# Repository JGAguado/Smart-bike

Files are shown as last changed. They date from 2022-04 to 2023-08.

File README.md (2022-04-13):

[][releases]
[](LICENSE)

[][maintenance]
[][buymecoffee]

# μBike
RP2040 microcontroller based board for standard bikes applications: lights control, GPS location with LoRa telemetry and display unit.

<p float="left">
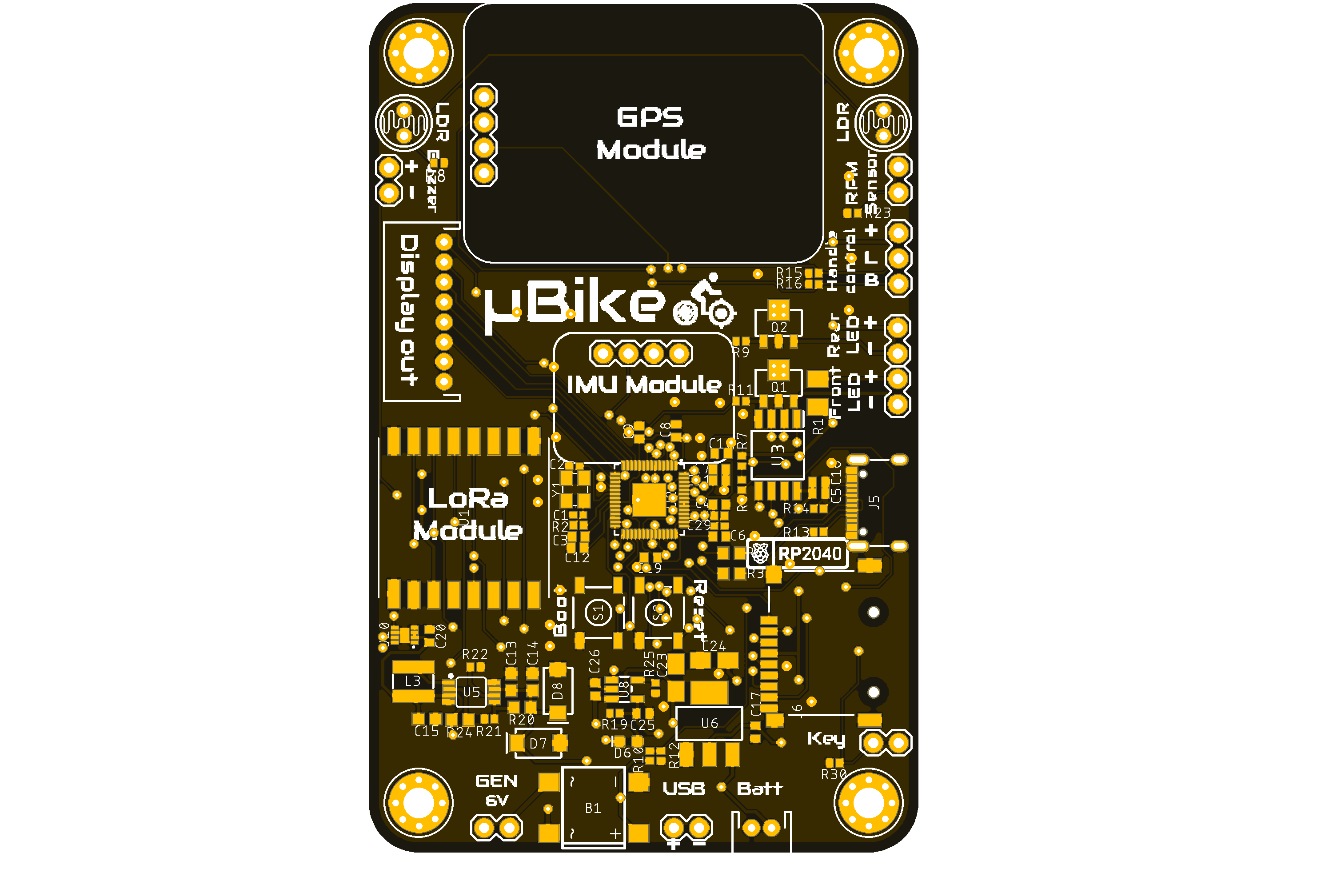
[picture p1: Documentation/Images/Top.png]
   
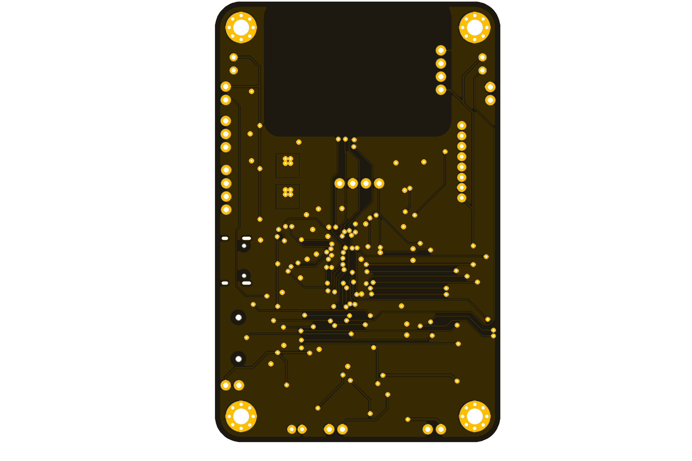
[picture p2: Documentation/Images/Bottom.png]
      
</p>

## Project tree
---

<li><a href="./uBike/Design/">Design</a></li>
<li><a href="./uBike/Documentation/">Documentation</a></li>

<li><a href="./README.md">README.md</a></li>

## Acknowledgments
---
 * [SparkFun Thing Plus RP2040](https://github.com/sparkfun/SparkFun_Thing_Plus-RP2040) - This board was used as inspiration for the layout design of the μBike

[releases-shield]: https://img.shields.io/github/release/JGAguado/uBike.svg?style=for-the-badge
[releases]: https://github.com/JGAguado/Fuel_Tracker/releases

[license-shield]: https://img.shields.io/badge/License-CC%20BY--NC--SA%204.0-lightgrey.svg?style=for-the-badge

[maintenance-shield]: https://img.shields.io/badge/maintainer-J.%20G.%20Aguado-blue.svg?style=for-the-badge
[maintenance]: https://github.com/JGAguado

[buymecoffee-shield]: https://img.shields.io/badge/buy%20me%20a%20coffee-support-yellow.svg?style=for-the-badge
[buymecoffee]: https://www.buymeacoffee.com/J.G.Aguado

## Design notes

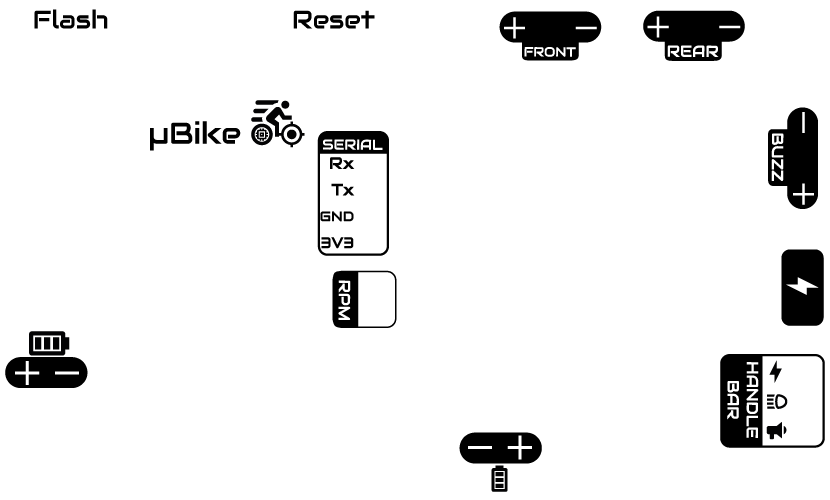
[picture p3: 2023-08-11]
Documentation/Silkscreen/Top.png

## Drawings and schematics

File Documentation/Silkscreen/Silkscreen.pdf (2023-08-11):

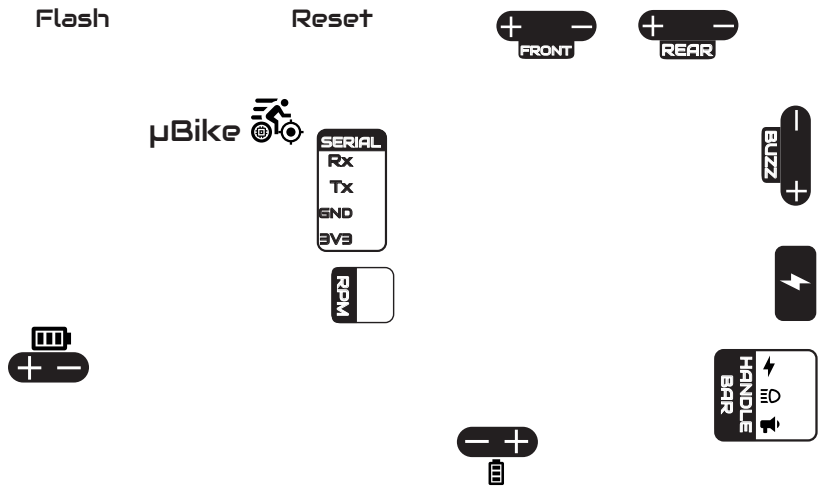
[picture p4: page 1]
Flash; Reset; GND; SERIAL; HANDLE BAR; REAR; BUZZ; FRONT; RPM; µBike

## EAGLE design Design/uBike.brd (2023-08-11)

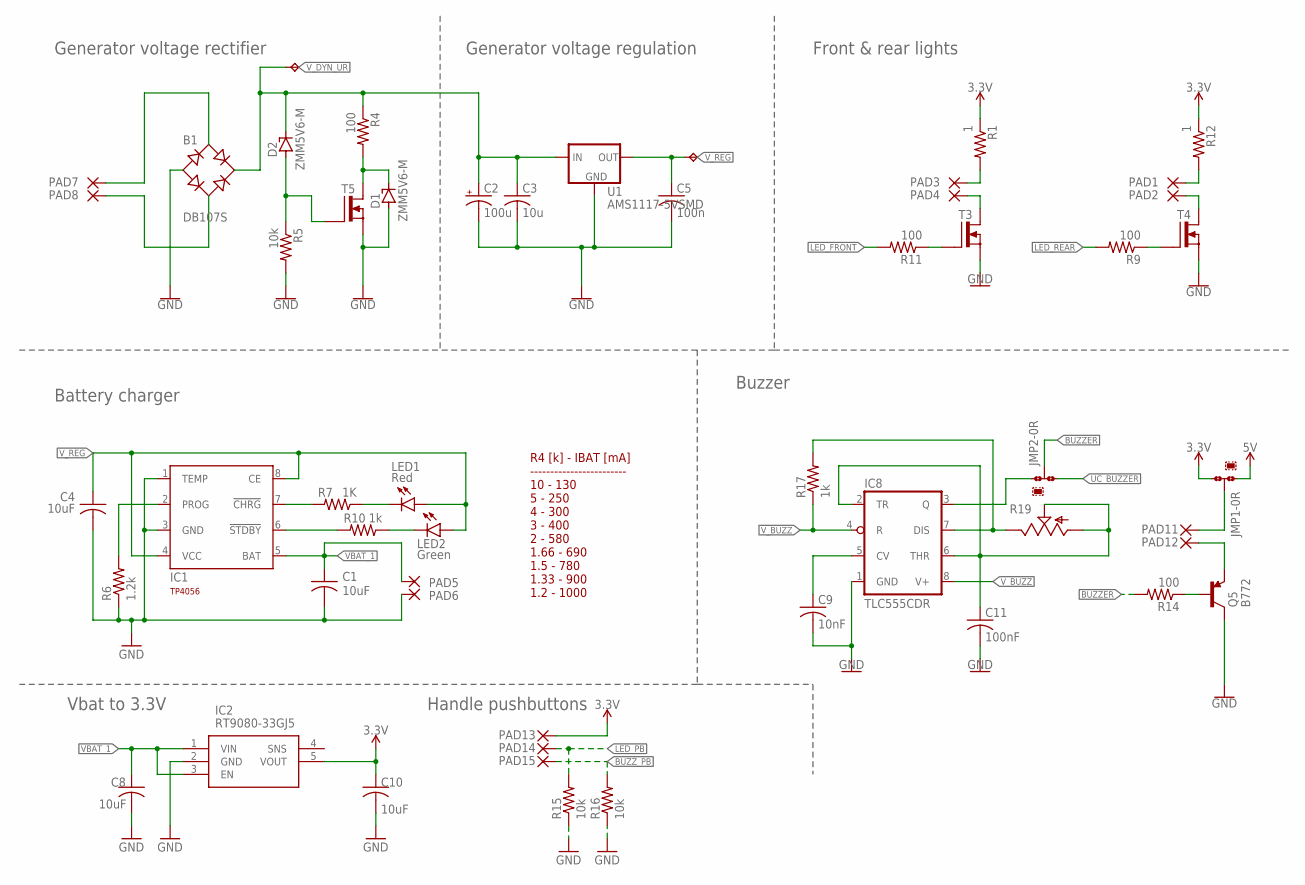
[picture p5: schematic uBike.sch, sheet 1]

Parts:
B1: DB107S; DBS; LCSC C5377
C1, C4, C8, C10: 10uF; C0603
C2: 100u; B/3528-21R; LCSC C16133
C3: 10u; C0603
C5: 100n; C0603
C9: 10nF; C0603
C11: 100nF; C0603
D1, D2: ZMM5V6-M; MELF-MLL34
IC1: TP4056; SOT23-8; LCSC C16581
IC2: RT9080-33GJ5; SOT94P280X100-5N; LCSC C841192
IC8: TLC555CDR; SO08; LCSC C6986
JMP1, JMP2: 0R-JUMPA; A0R-JMP
LED1: Red; LED_0603
LED2: Green; LED_0603
PAD1, PAD2, PAD3, PAD4, PAD5, PAD6, PAD7, PAD8, PAD11, PAD12, PAD13, PAD14, PAD15: SMD2; SMD1,27-2,54
Q5: B772; SOT89; LCSC C24278
R1, R12: 1; R1206; LCSC C17928
R4: 100; 0402; LCSC C17928
R5: 10k; 0402; LCSC C17928
R6: 1.2k; 0402
R7: 1K; 0402
R9, R11, R14: 100; 0402
R10, R17: 1k; 0402
R15, R16: 10k; 0402
R19: TRIM_US-RJ9W; RJ9W
T3, T4, T5: T_N-MOSFET_2N7002_CHANGJ_SOT23-GSD; SOT23
TP1, TP3: TPTP15R; TP15R
U1: AMS1117-5VSMD; SOT223

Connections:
3.3V: C10.1, IC2.5 (VOUT), JMP1.3, PAD13.1, R1.1, R12.1; also elsewhere on the board
5V: JMP1.1
BUZZER: JMP2.2, R14.2
BUZZ_PB: PAD15.1, R16.2; also elsewhere on the board
GND: B1.-, C1.2, C2.-, C3.2, C4.2, C5.2, C8.2, C9.2, C10.2, C11.2, D1.A, IC1.1 (TEMP), IC1.3 (GND), IC2.2 (GND), IC8.1 (GND), PAD6.1, Q5.2 (C), R5.2, R6.1, R15.1, R16.1, T3.2 (S), T4.2 (S), T5.2 (S), U1.1 (GND); also elsewhere on the board
LED_FRONT: R11.2; also elsewhere on the board
LED_PB: PAD14.1, R15.2; also elsewhere on the board
LED_REAR: R9.2; also elsewhere on the board
unnamed: PAD3.1, R1.2
unnamed: R9.1, T4.1 (G)
unnamed: IC1.6 (!STDBY), R10.2
unnamed: PAD4.1, T3.3 (D)
unnamed: R11.1, T3.1 (G)
unnamed: PAD2.1, T4.3 (D)
unnamed: D2.A, R5.1, T5.1 (G)
unnamed: D1.C, R4.2, T5.3 (D)
unnamed: B1.AC2, PAD8.1
unnamed: LED1.C, R7.1
unnamed: LED2.C, R10.1
unnamed: IC1.2 (PROG), R6.2
unnamed: B1.AC1, PAD7.1
unnamed: IC1.7 (!CHRG), R7.2
unnamed: Q5.1 (B), R14.1
unnamed: PAD12.1, Q5.3 (E)
unnamed: JMP1.2, PAD11.1
unnamed: PAD1.1, R12.2
unnamed: IC8.7 (DIS), R17.2, R19.E
unnamed: C11.1, IC8.2 (TR), IC8.6 (THR), R19.A, R19.S
unnamed: IC8.3 (Q), JMP2.1
unnamed: C9.1, IC8.5 (CV)
UC_BUZZER: JMP2.3; also elsewhere on the board
VBAT_1: C1.1, C8.1, IC1.5 (BAT), IC2.1 (VIN), IC2.3 (EN), PAD5.1
V_BUZZ: IC8.4 (R), IC8.8 (V+), R17.1
V_DYN_UR: B1.+, C2.+, C3.1, D2.C, R4.1, TP1.TP, U1.3 (IN)
V_REG: C4.1, C5.1, IC1.4 (VCC), IC1.8 (CE), LED1.A, LED2.A, TP3.TP, U1.2 (OUT)

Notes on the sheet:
Battery charger
R4 [k] - IBAT [mA] ------------------------ 10 - 130 5 - 250 4 - 300 3 - 400 2 - 580 1.66 - 690 1.5 - 780 1.33 - 900 1.2 - 1000
Generator voltage rectifier
Generator voltage regulation
Vbat to 3.3V
Front & rear lights
Buzzer
Handle pushbuttons

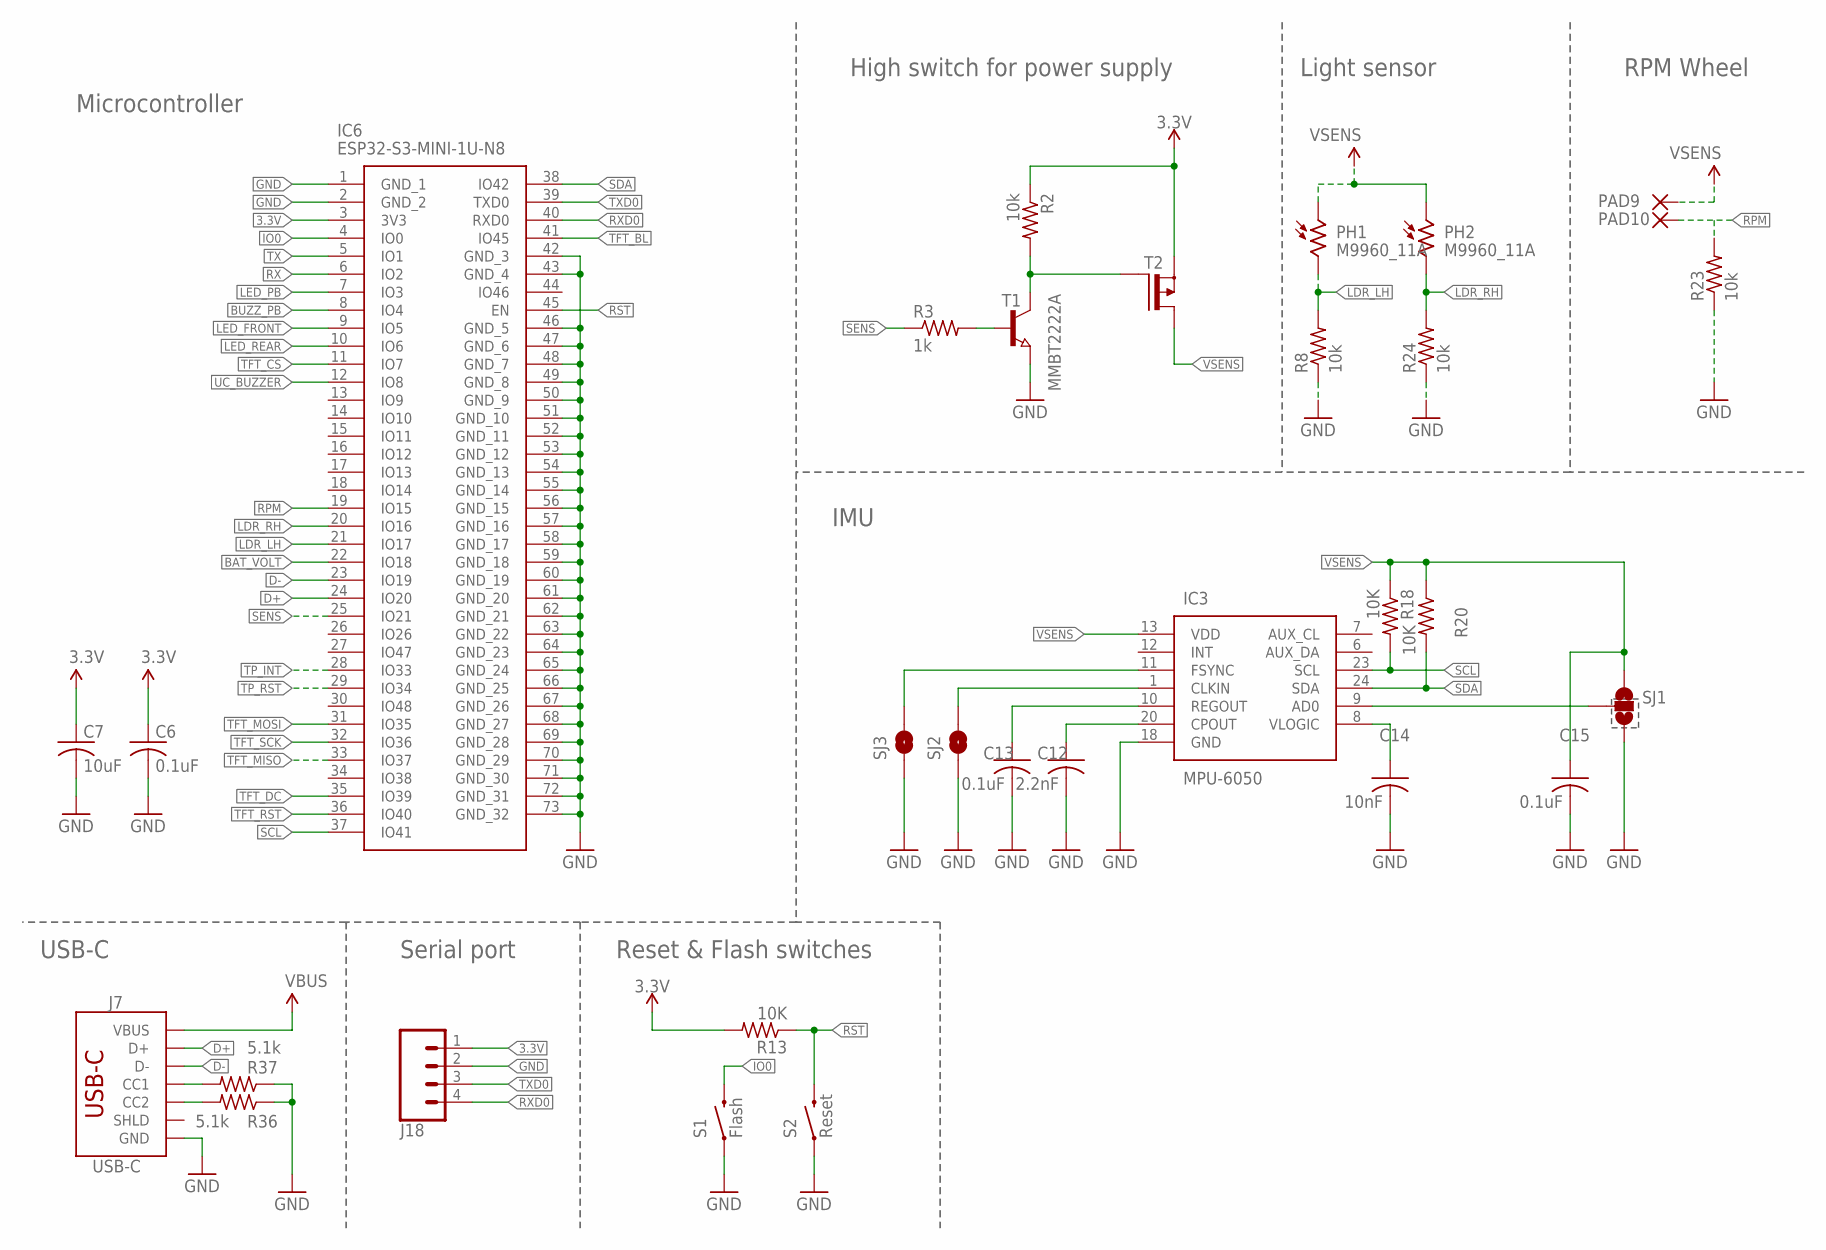
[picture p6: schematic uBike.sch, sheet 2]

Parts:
C6, C13, C15: 0.1uF; C0603
C7: 10uF; C0603
C12: 2.2nF; C0603
C14: 10nF; C0603
IC3: MPU-6050; MPU6050
IC6: ESP32-S3-MINI-1U-N8; ESP32S3MINI1UN8
J7: USB-C; USB-C-16P-4LAYER-ISOLATED; LCSC C2765186
J18: CONN_04PTH; 1X04
PAD9, PAD10: SMD2; SMD1,27-2,54
PH1, PH2: M9960_11A; M9960
R2, R8, R23, R24: 10k; 0402
R3: 1k; 0402
R13, R18, R20: 10K; 0402
R36, R37: 5.1k; R0603
S1: Flash; TACTILE_SWITCH_SMD_5.2MM
S2: Reset; TACTILE_SWITCH_SMD_5.2MM
SJ1: SOLDERJUMPER_2WAYPASTE2&3; SJ_3_PASTE2&3
SJ2, SJ3: SOLDERJUMPERTRACE; SJ_2S-TRACE
T1: MMBT2222A; SOT23
T2: T_P-MOSFET_SI2301CDS-T1-GE3_VISHAY_SOT23-GSD; SOT23

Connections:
3.3V: C6.1, C7.1, IC6.3 (3V3), J18.1, R2.1, R13.2, T2.2 (S); also elsewhere on the board
BAT_VOLT: IC6.22 (IO18); also elsewhere on the board
BUZZ_PB: IC6.8 (IO4); also elsewhere on the board
CC3: J7.B5 (CC2), R36.2
CC4: J7.A5 (CC1), R37.2
D+: IC6.24 (IO20), J7.A6 (D+), J7.B6 (D+)
D-: IC6.23 (IO19), J7.A7 (D-), J7.B7 (D-)
GND: C6.2, C7.2, C12.2, C13.2, C14.2, C15.2, IC3.18 (GND), IC6.1 (GND_1), IC6.2 (GND_2), IC6.42 (GND_3), IC6.43 (GND_4), IC6.46 (GND_5), IC6.47 (GND_6), IC6.48 (GND_7), IC6.49 (GND_8), IC6.50 (GND_9), IC6.51 (GND_10), IC6.52 (GND_11), IC6.53 (GND_12), IC6.54 (GND_13), IC6.55 (GND_14), IC6.56 (GND_15), IC6.57 (GND_16), IC6.58 (GND_17), IC6.59 (GND_18), IC6.60 (GND_19), IC6.61 (GND_20), IC6.62 (GND_21), IC6.63 (GND_22), IC6.64 (GND_23), IC6.65 (GND_24), IC6.66 (GND_25), IC6.67 (GND_26), IC6.68 (GND_27), IC6.69 (GND_28), IC6.70 (GND_29), IC6.71 (GND_30), IC6.72 (GND_31), IC6.73 (GND_32), J7.GND, J7.GND2 (GND), J18.2, R8.1, R23.1, R24.1, R36.1, R37.1, S1.1, S2.1, SJ1.3, SJ2.1, SJ3.1, T1.2 (E); also elsewhere on the board
IO0: IC6.4 (IO0), S1.3 (2)
LDR_LH: IC6.21 (IO17), PH1.2, R8.2
LDR_RH: IC6.20 (IO16), PH2.2, R24.2
LED_FRONT: IC6.9 (IO5); also elsewhere on the board
LED_PB: IC6.7 (IO3); also elsewhere on the board
LED_REAR: IC6.10 (IO6); also elsewhere on the board
unnamed: R2.2, T1.3 (C), T2.1 (G)
unnamed: R3.2, T1.1 (B)
unnamed: IC3.11 (FSYNC), SJ3.2
unnamed: IC3.1 (CLKIN), SJ2.2
unnamed: C13.1, IC3.10 (REGOUT)
unnamed: C12.1, IC3.20 (CPOUT)
unnamed: C14.1, IC3.8 (VLOGIC)
unnamed: IC3.9 (AD0), SJ1.2
RPM: IC6.19 (IO15), PAD10.1, R23.2
RST: IC6.45 (EN), R13.1, S2.3 (2)
RX: IC6.6 (IO2)
RXD0: IC6.40 (RXD0), J18.4
SCL: IC3.23 (SCL), IC6.37 (IO41), R18.2; also elsewhere on the board
SDA: IC3.24 (SDA), IC6.38 (IO42), R20.2; also elsewhere on the board
SENS: IC6.25 (IO21), R3.1
TFT_BL: IC6.41 (IO45); also elsewhere on the board
TFT_CS: IC6.11 (IO7); also elsewhere on the board
TFT_DC: IC6.35 (IO39); also elsewhere on the board
TFT_MISO: IC6.33 (IO37)
TFT_MOSI: IC6.31 (IO35); also elsewhere on the board
TFT_RST: IC6.36 (IO40); also elsewhere on the board
TFT_SCK: IC6.32 (IO36); also elsewhere on the board
TP_INT: IC6.28 (IO33); also elsewhere on the board
TP_RST: IC6.29 (IO34); also elsewhere on the board
TX: IC6.5 (IO1)
TXD0: IC6.39 (TXD0), J18.3
UC_BUZZER: IC6.12 (IO8); also elsewhere on the board
VBUS: J7.VBUS1 (VBUS), J7.VBUS2 (VBUS); also elsewhere on the board
VSENS: C15.1, IC3.13 (VDD), PAD9.1, PH1.1, PH2.1, R18.1, R20.1, SJ1.1, T2.3 (D); also elsewhere on the board

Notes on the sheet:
Reset & Flash switches
Serial port
Microcontroller
USB-C
High switch for power supply
Light sensor
RPM Wheel
IMU

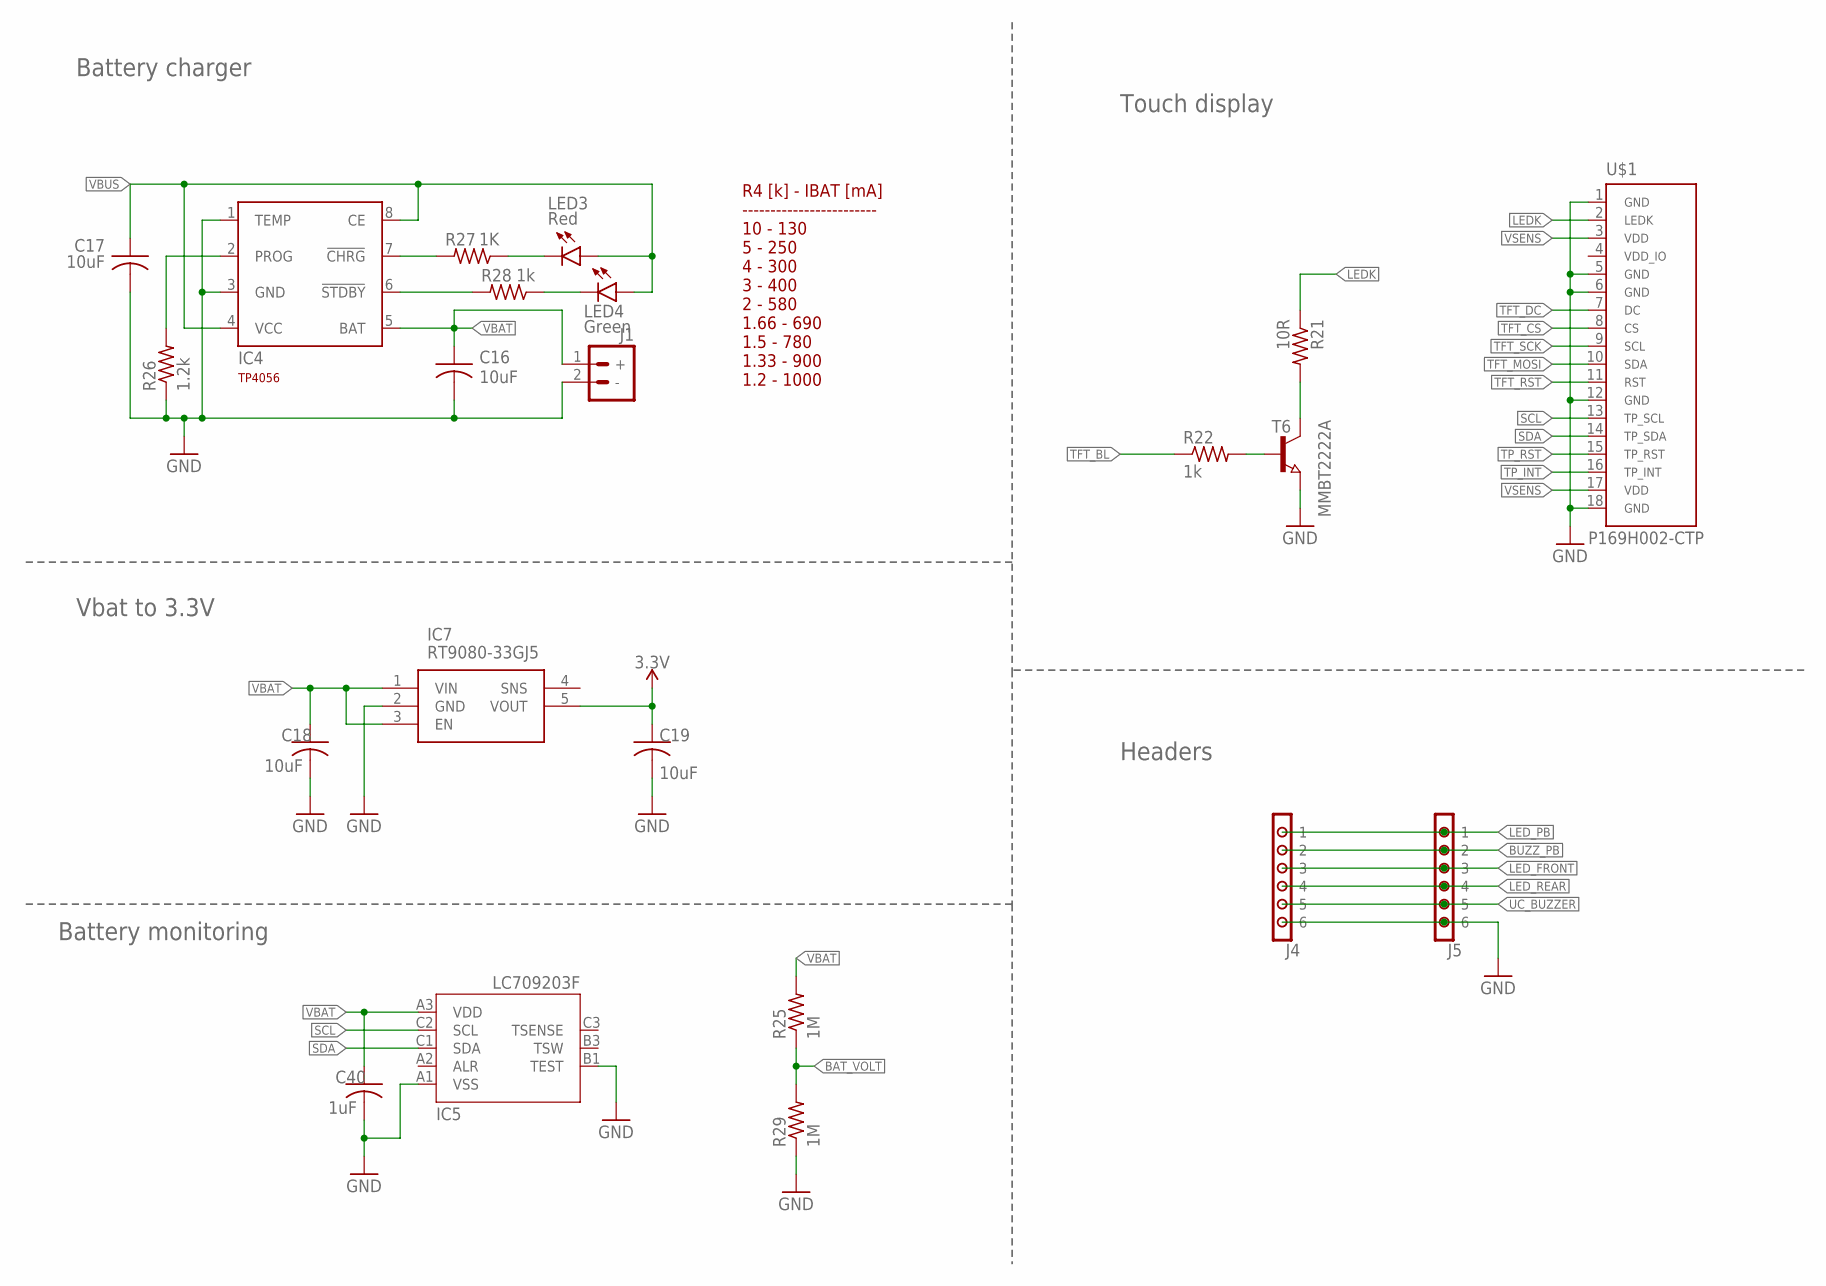
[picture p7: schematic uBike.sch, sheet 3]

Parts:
C16, C17, C18, C19: 10uF; C0603
C40: 1uF; C0603
IC4: TP4056; SOT23-8
IC5: LC709203F/MH; WLCSP9; LCSC C184366
IC7: RT9080-33GJ5; SOT94P280X100-5N; LCSC C841192
J1: BAT_CONN-JST-2MM-SMT; JST-2-SMD; LCSC C3029440
J4, J5: CONN_06; 1X06
LED3: Red; LED_0603
LED4: Green; LED_0603
R21: 10R; 0402
R22, R28: 1k; 0402
R25, R29: 1M; 0402
R26: 1.2k; 0402
R27: 1K; 0402
T6: MMBT2222A; SOT23
U$1: P169H002-CTP; FPC_18_0.5MM_BOTTOM; LCSC C262326

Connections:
3.3V: C19.1, IC7.5 (VOUT); also elsewhere on the board
BAT_VOLT: R25.1, R29.2; also elsewhere on the board
BUZZ_PB: J4.2, J5.2; also elsewhere on the board
GND: C16.2, C17.2, C18.2, C19.2, C40.2, IC4.1 (TEMP), IC4.3 (GND), IC5.A1 (VSS), IC5.B1 (TEST), IC7.2 (GND), J1.2 (-), J4.6, J5.6, R26.1, R29.1, T6.2 (E), U$1.1, U$1.5, U$1.6, U$1.12, U$1.18; also elsewhere on the board
LEDK: R21.1, U$1.2
LED_FRONT: J4.3, J5.3; also elsewhere on the board
LED_PB: J4.1, J5.1; also elsewhere on the board
LED_REAR: J4.4, J5.4; also elsewhere on the board
unnamed: R21.2, T6.3 (C)
unnamed: R22.2, T6.1 (B)
unnamed: IC4.6 (!STDBY), R28.2
unnamed: LED3.C, R27.1
unnamed: LED4.C, R28.1
unnamed: IC4.2 (PROG), R26.2
unnamed: IC4.7 (!CHRG), R27.2
SCL: IC5.C2 (SCL), U$1.13; also elsewhere on the board
SDA: IC5.C1 (SDA), U$1.14; also elsewhere on the board
TFT_BL: R22.1; also elsewhere on the board
TFT_CS: U$1.8; also elsewhere on the board
TFT_DC: U$1.7; also elsewhere on the board
TFT_MOSI: U$1.10; also elsewhere on the board
TFT_RST: U$1.11; also elsewhere on the board
TFT_SCK: U$1.9; also elsewhere on the board
TP_INT: U$1.16; also elsewhere on the board
TP_RST: U$1.15; also elsewhere on the board
UC_BUZZER: J4.5, J5.5; also elsewhere on the board
VBAT: C16.1, C18.1, C40.1, IC4.5 (BAT), IC5.A3 (VDD), IC7.1 (VIN), IC7.3 (EN), J1.1 (+), R25.2
VBUS: C17.1, IC4.4 (VCC), IC4.8 (CE), LED3.A, LED4.A; also elsewhere on the board
VSENS: U$1.3, U$1.17; also elsewhere on the board

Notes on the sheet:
Battery charger
R4 [k] - IBAT [mA] ------------------------ 10 - 130 5 - 250 4 - 300 3 - 400 2 - 580 1.66 - 690 1.5 - 780 1.33 - 900 1.2 - 1000
Vbat to 3.3V
Touch display
Battery monitoring
Headers

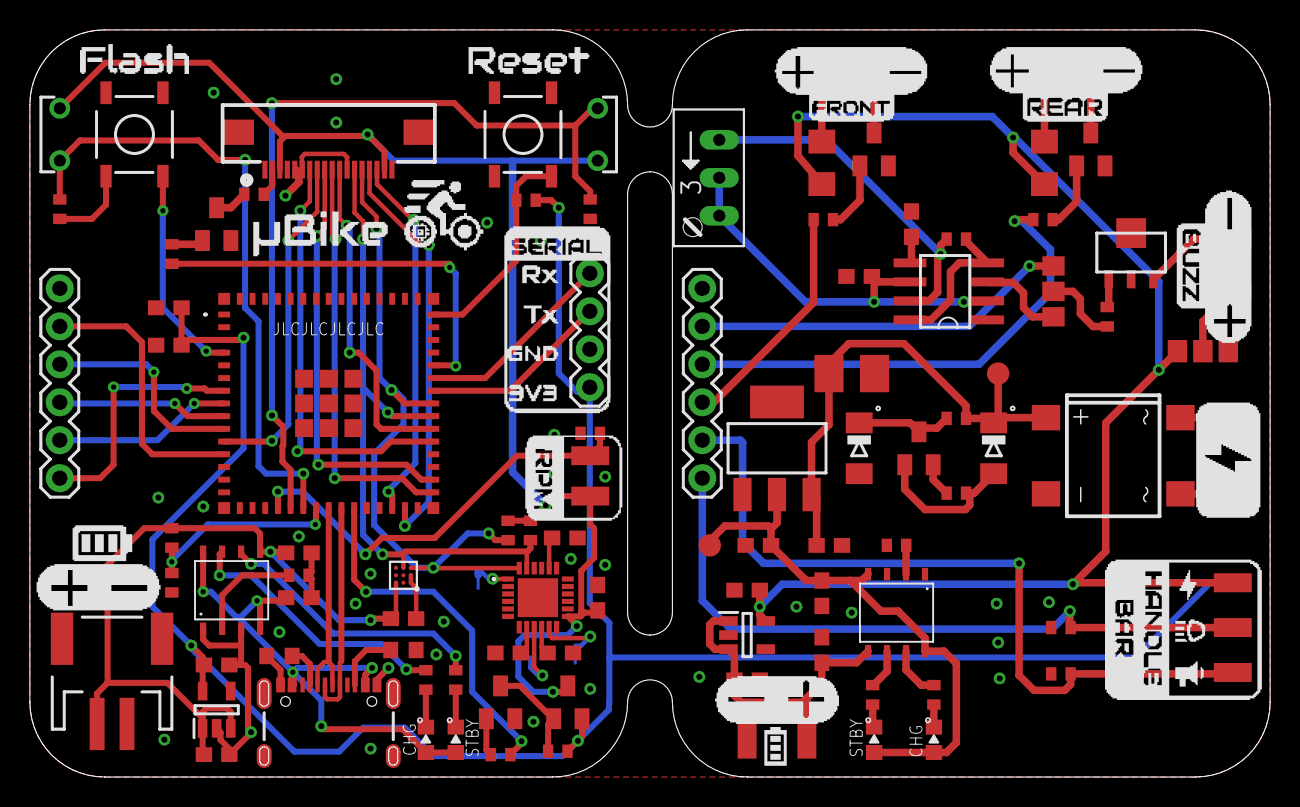
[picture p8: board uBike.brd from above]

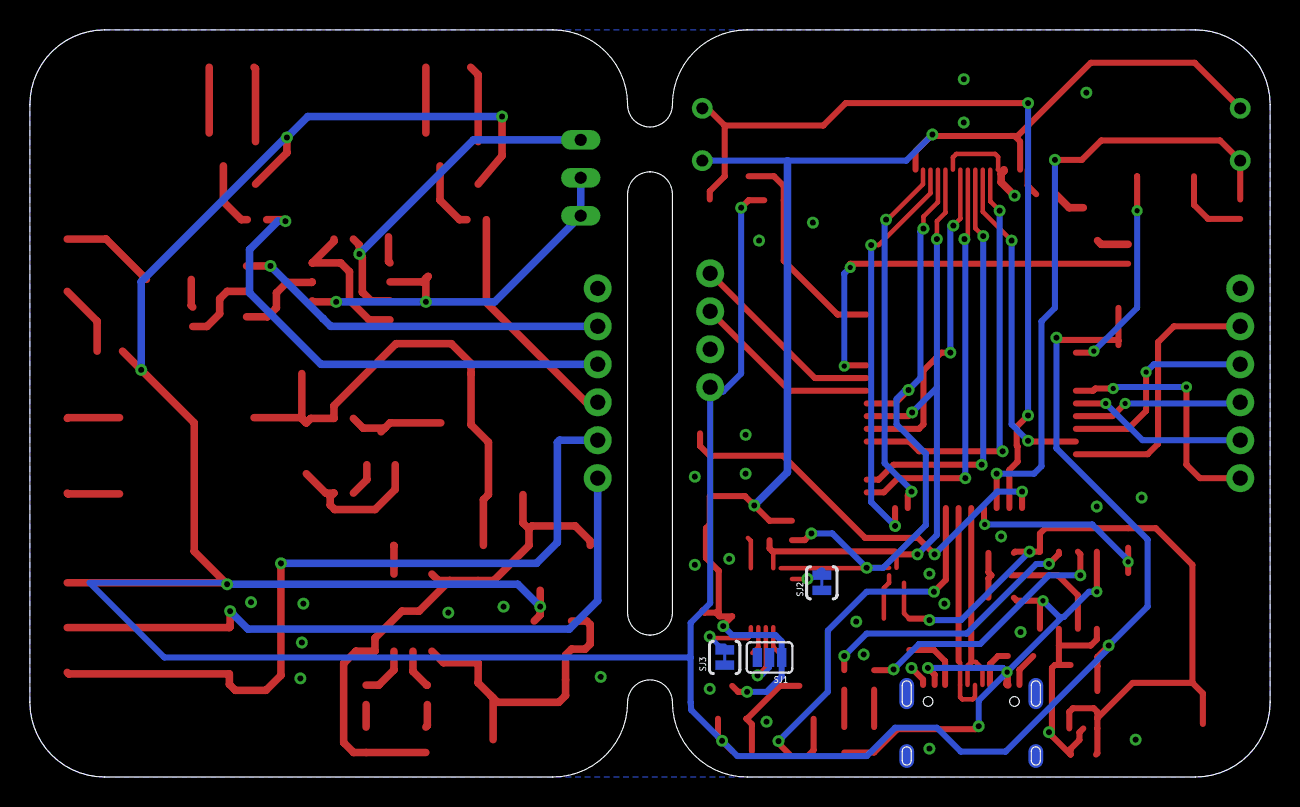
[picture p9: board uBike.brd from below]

Board: 2 copper layers, 83.0 x 50.0 mm, 106 parts (3 on the bottom side), 76 nets.

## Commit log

2022-03-29 First design files for uBike
    [uBike.brd, uBike.sch]
2022-03-29 First documentation images and silkscreen files
2022-03-29 New branch replacing Accel & Temp IC with pre-assembled module.
    [uBike.brd, uBike.sch]
2022-03-29 Added Documentation images & Silkscreen design
2022-04-11 Fixed U3 component with W25Q128JVSIQ
    [uBike.brd, uBike.sch]
2022-04-11 First commit in the branch
    [uBike.brd]
2022-04-13 Updated schematic
    [uBike.sch]
2023-08-11 Frozen design for August 23 manufacturing batch
    [uBike.brd, uBike.sch]
2023-08-11 Silkscreen design

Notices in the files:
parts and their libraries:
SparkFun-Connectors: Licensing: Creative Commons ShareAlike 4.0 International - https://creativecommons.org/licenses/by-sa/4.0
